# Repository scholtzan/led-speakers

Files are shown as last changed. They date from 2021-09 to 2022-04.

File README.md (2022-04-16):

# 3D Printed Reactive LED Speakers

This repository contains all the model files, assembly instructions and code files for building reactive LED speakers.

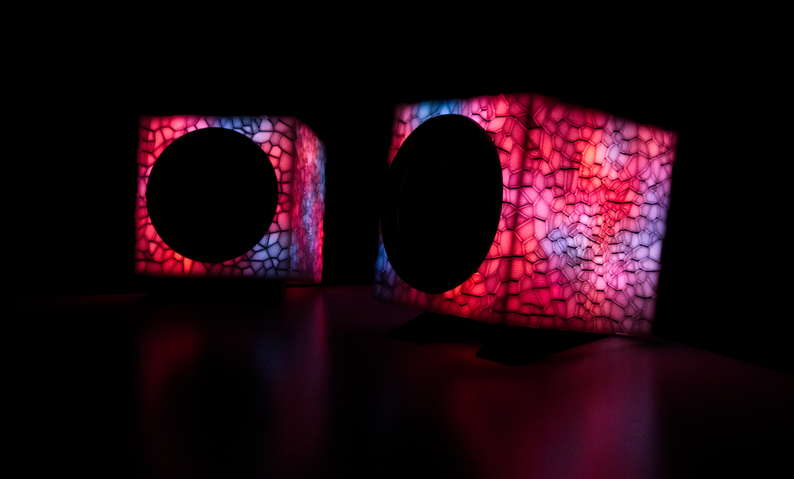
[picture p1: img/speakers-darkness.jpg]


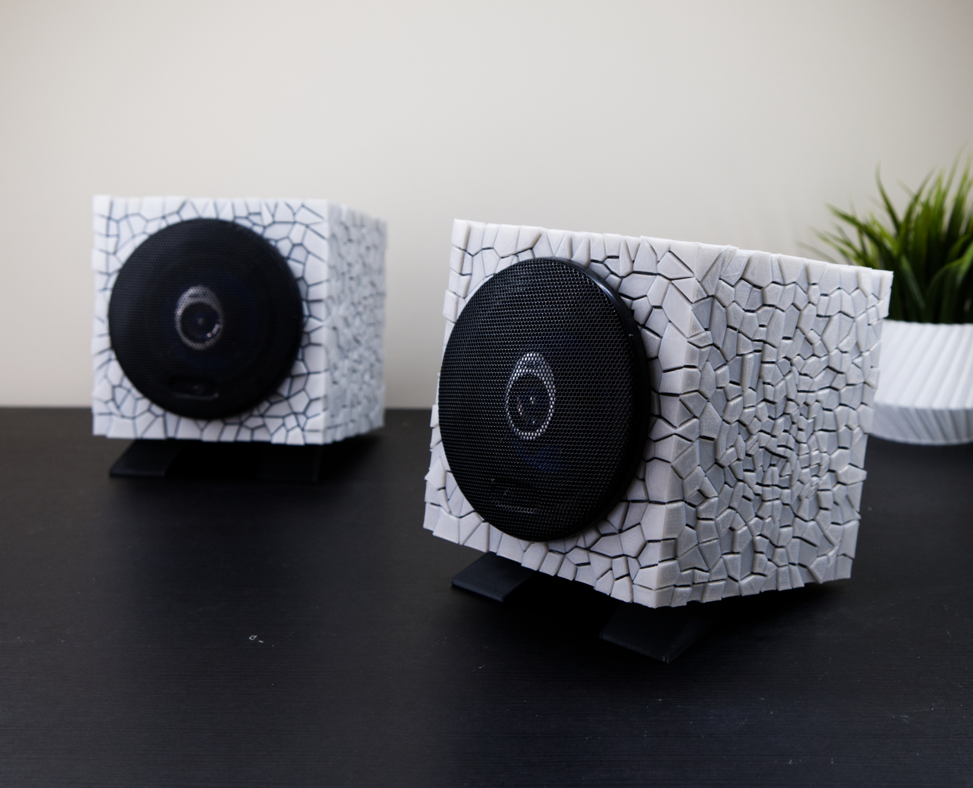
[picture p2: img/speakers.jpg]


## Demo

_Watch a demo of the speakers on Youtube:_

Youtube video (https://www.youtube.com/watch?v=SGH6p20TAoc)

## Overview

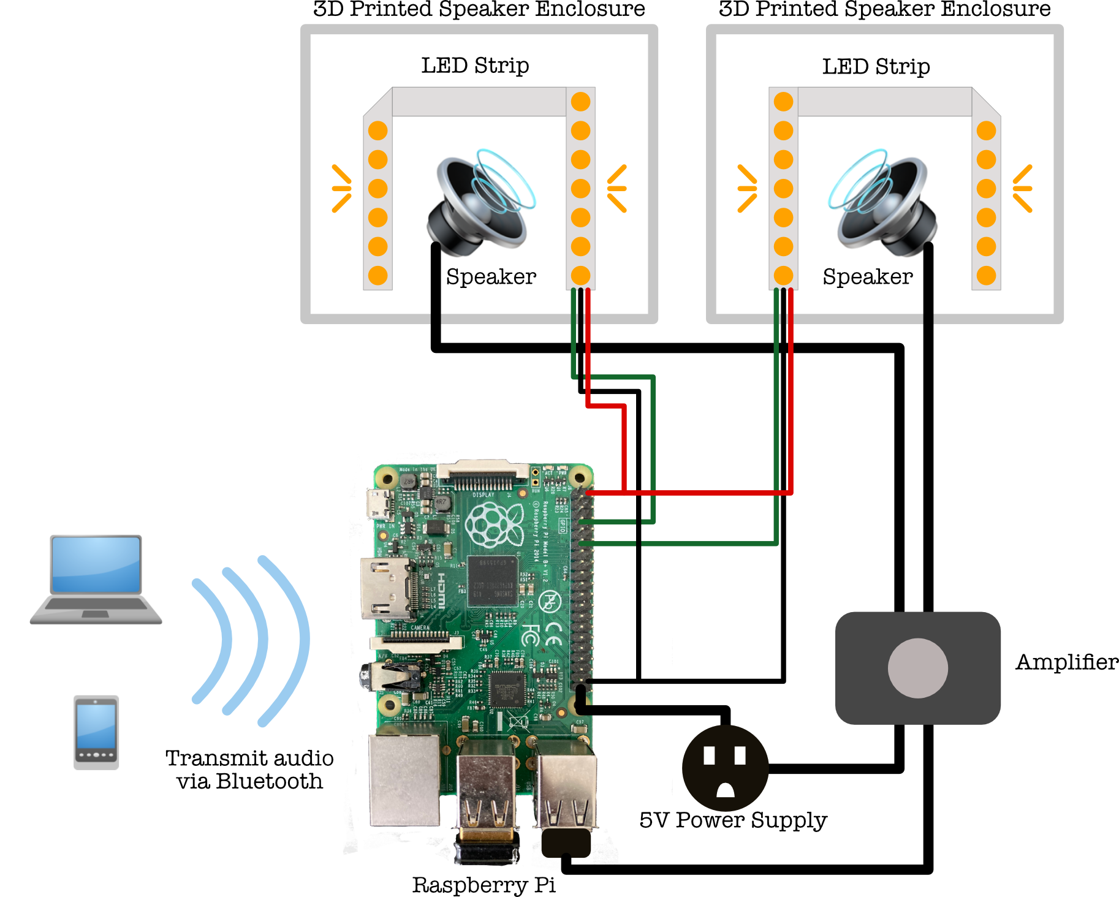
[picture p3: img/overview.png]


The entire setup consists of two speakers which are composed of a 3D printed enclosure that contains the speaker cone and a 1.5m long LED strip.
The enclosure is mainly printed from transparent PLA+ with some black accents. The speakers are connected to an amplifier which gets its audio
input from a Raspberry Pi. Devices, like phones or PCs can connect to the Raspberry Pi via Bluetooth to play audio. The audio input is processed 
to create different visual patterns on the connected LED strips. 

## Required Materials

* Raspberry Pi
    * Ideally a Raspberry Pi 4, since it has in-built Bluetooth and Wifi
    * Older versions also work but need additional dongles for Bluetooth
* 5V power supply
* Amplifier
* 3m RGB LED strip
    * 1.5m for each speaker
* 4-inch speakers
* 4mm Dual Banana Jack Socket Binding Post to 2 Screws Adapter Connector
    * For connecting the Amplifier to the Speakers
* Wire
    * For connecting all the components
* Heat shrink tubes
    * For insulating soldered wires
* Soldering iron + solder
* Hot glue gun + Hot glue
* Clear PLA+
    * Enclosure
* Black PLA+
    * Inner LED cage, stand, enclosure
* [optional] Glow-in-the-dark filament
    * The last few upper layers can be printed with Glow-in-the-dark filament for some interesting glow-in-the-dark effects

## 3D Printed Enclosure

The speaker enclosure consists of multiple parts that can be found in the `model/` directory.

The outer enclosure walls are printed from clear PLA+. For a better contrast of the rough structure, the gaps are printed in black PLA.
To change filament mid-print, the [Multicolor prints with a single extruder in Cura](https://github.com/scholtzan/cura-multicolor-single-extruder) plugin
can be used.


_Printed walls_

The LED strip will be cut into smaller strips that will get attached to an inner cage to stay in place.
All parts of the cage are printed in PLA and glued together using hot glue.


_Parts for assembling the inner cage_

The assembled cage with the LEDs glued on is then attached to one of the enclosure walls.

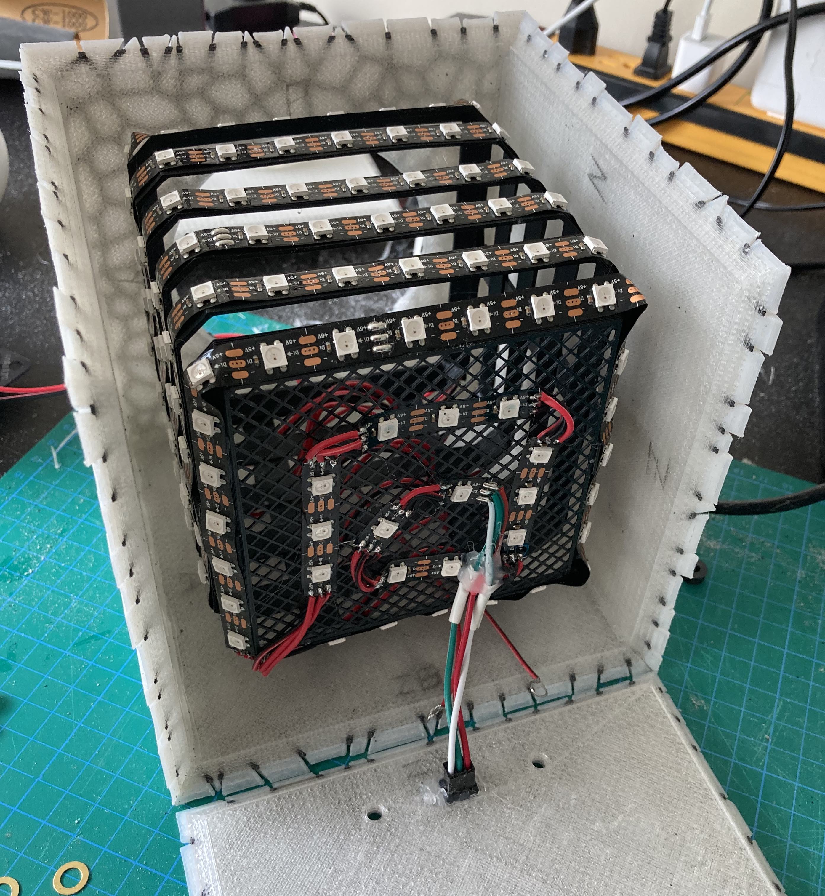
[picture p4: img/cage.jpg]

_Assembled cage with LEDs_

### Print Settings

**Walls**:
* Infill: 50%
* Infill Pattern: Gyroid
* Layer Height: 0.3mm
* Support: no

**Inner cage:**
* Infill: 15%
* Layer Height: 0.3mm
* Support: no

## Raspberry Pi Setup

Currently, only USB input is supported. Connect the amplifier to the Raspberry Pi using USB and connect the LED strips to the SPI pins
of the Raspberry Pi. A 5V power supply is used to power the Raspberry Pi as well as the LED strips. The amplifier uses a separate power supply.

All of these components (except for the amplifier) are placed in a separate printed enclosure.

### Audio Setup

_Based on [Another How to turn your Pi in a Bluetooth Speaker Tutorial](https://forums.raspberrypi.com/viewtopic.php?t=235519)_

Install Pulseaudio and bluetooth module:
```sudo apt-get install pulseaudio pulseaudio-module-bluetooth```

Add user to group `bluetooth`:
```
sudo usermod -a -G bluetooth pi
sudo reboot
```

Make discoverable:
```
sudo nano /etc/bluetooth/main.conf

...
Class = 0x41C
DiscoverableTimeout = 0
...

sudo systemctl restart bluetooth
```

In `bluetoothctl`, setup Bluetooth:
```
pi@raspberrypi:~ $ bluetoothctl
[NEW] Controller XX:XX:XX:XX:XX:XX raspberrypi [default]
[bluetooth]# power on
Changing power on succeeded
[bluetooth]# discoverable on
Changing discoverable on succeeded
[CHG] Controller XX:XX:XX:XX:XX:XX Discoverable: yes
[bluetooth]# pairable on
Changing pairable on succeeded
[bluetooth]# agent on
Agent registered
[bluetooth]# default-agent
Default agent request successful
[bluetooth]# quit
Agent unregistered
[DEL] Controller XX:XX:XX:XX:XX:XX raspberrypi [default]
```

Start Pulseaudio and check status:
```
pulseaudio --start

sudo systemctl status bluetooth
```

Start Pulseaudio on boot
```
systemctl --user enable pulseaudio
```

Auto-pairing
```
sudo apt-get install bluez-tools

sudo nano /etc/systemd/system/bt-agent.service

[Unit]
Description=Bluetooth Auth Agent
After=bluetooth.service
PartOf=bluetooth.service

[Service]
Type=simple
ExecStart=/usr/bin/bt-agent -c NoInputNoOutput

[Install]
WantedBy=bluetooth.target

sudo systemctl enable bt-agent
```

Disable onboard Bluetooth module in favour of Bluetooth dongle:
```
sudo nano /etc/modprobe.d/blacklist-bluetooth.conf

blacklist btbcm
blacklist hci_uart
```

Controlling volume:
```
sudo nano /etc/systemd/system/bluetooth.target.wants/bluetooth.service

...
ExecStart=/usr/lib/bluetooth/bluetoothd --noplugin=avrcp
...
```

### LED

Use SPI for LED strip:
```
/boot/cmdline.txt 
```

append 
```
spidev.bufsiz=32768

core_freq=500
core_freq_min=500
```

## Software

### Server

Install [cross](https://github.com/rust-embedded/cross)

Build docker container with libpulse installed:

`docker build -t rbp-cross . `

Build project

`cross build --target=armv7-unknown-linux-gnueabihf --release`

### Web App

Go to the `web/` folder: `cd web/`

Update the `.env` file and set the correct host and ports.

To build the web app run: `make`

### Installation

Once the server and web app have been built successfully, copy the `led_speakers` binary, the `web/static` directory and the `config.json` file on to the Raspberry Pi.

The software can be manually started by running `./led_speakers` and the web app will be ready to be accessed under the configured host and port.

Settings can be changed in the `config.json` file.

To start the software automatically when booting, create a custom systemd service:

`sudo nano ~/.config/systemd/user/led-speakers.service`

```
[Unit]
Description=LED Speakers Service

[Service]
Type=idle
ExecStart=/home/pi/led_speakers
Restart=on-failure
RestartSec=60

[Install]
WantedBy=default.target
```

To enable the service:

```
systemctl --user enable led-speakers.service
systemctl --user daemon-reload
```

### Settings

Settings can be changed in the `config.json` file:

```json
{
    // available visualizations and default configurations
    "visualizations": {
        "rotating_viz": {
            "pretty_name": "Rotating Viz",
            "speed": 5.0,
            "falloff": 0.1
        },
        "sparkle_viz": {
            "pretty_name": "Sparkle Viz",
            "falloff": 0.1,
            "speed": 5.0,
            "max_ignite": 2.0
        },
        "solid_viz": {
            "pretty_name": "Solid Viz"
        },
        "center_viz": {
            "pretty_name": "Center Viz"
        },
        "solid_beat_viz": {
            "pretty_name": "Solid Beat Viz",
            "fade_colors": true,
            "fade_duration": 20
        },
        "fading_beat_viz": {
            "pretty_name": "Fading Beat Viz",
            "fade_duration": 1,
            "fade_threshold": 10,
            "frequency_magnitude_buffer_size": 300
        },
        "blend_viz": {
            "pretty_name": "Blend Viz",
            "spread": 6,
            "blend_speed": 3,
            "offset_weight": 1,
            "blend_factor": 10
        }
    },
    // configures the pins that control the LED strip
    "output": {
        "left": {
            "spi": "/dev/spidev0.0",
            "total_leds": 150
        },
        "right": {
            "spi": "/dev/spidev1.0",
            "total_leds": 150
        }
    },
    // default themes
    "themes": [
        {
            "name": "Rainbow",
            "colors": [
                [255, 0, 0],
                [255, 100, 0],
                [255, 200, 0],
                [100, 255, 0],
                [0, 255, 0],
                [0, 255, 100],
                [0, 255, 255],
                [0, 100, 255],
                [0, 0, 255],
                [100, 0, 255],
                [255, 0, 255]
            ]
        },
        {
            "name": "Test Theme",
            "colors": [
                [255, 0, 0]
            ]    
        }
    ],
    // parameters for the audio transformation
    "transformer": {
        "sink": "alsa_output.usb-Generic_USB2.0_Device_20170726905959-00.analog-stereo",
        "fft_len": 3000,
        "total_bands": 6,
        "lower_cutoff": 50.0,
        "upper_cutoff": 10000.0,
        "monstercat": 50.0,
        "decay": 10.0,
        "buffer_size": 65535
    },
    // host and port web app is hosted under
    "server_host": "127.0.0.1",
    "server_port": "8000"
}
```

### More docs

More detailed docs about certain aspects of the software can be found in [`docs/`](https://github.com/scholtzan/led-speakers/tree/main/docs)

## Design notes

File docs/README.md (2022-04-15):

# Software docs

Some more information about the software doing the audio processing and visualizations can be found in this directory:

* [Audio Input](https://github.com/scholtzan/led-speakers/blob/main/docs/audio.md)
* [Audio Transformation](https://github.com/scholtzan/led-speakers/blob/main/docs/transform.md)
* [Visualization](https://github.com/scholtzan/led-speakers/blob/main/docs/visualization.md)

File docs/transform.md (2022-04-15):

# Audio Processing and Transformation

The `AudioTransformer` initializes a new audio stream and starts the FFT based on the audio samples written to the audio buffer.

[todo: add more docs]

## FFT

To get frequency information about the audio input (dividing into frequency components). Frequency components are sinus oscillations with certain amplitude an dphase. 
Sampling rate = average number of samples obtained in one second
Maximum frequency that can be observed = sampling rate / 2
Measurement duration = block length = number of samples to analyse

convert fft into smaller number of buckets reperesnting average magnitude of frequencies they represent
log magnitude instead of linear frequency

averaging spectra
* exponential mean
    * weighting is inversely propotional to age of result (oldest measurement taken into account least)

frequency magnitutes gets determined frequencies as input after FFT

frequency constant ~= 2.4

distribution coefficient = [-frequency constant; 0]

cutoff frequencies = [0; upper cutoff]

frequency = [0; 1]

upper cutoff = lower cutoff

band_frequency_magnitude = sqrt(avg_magnitude * (2 + n))

resampling/rebinning a spectrum
https://dsp.stackexchange.com/questions/129/how-can-i-compute-a-log-spaced-power-spectrum/2098#2098

The log scale more closely matches our perception of the sound spectrum.

Our perception makes us feel that C1 is the same distance from C2 as C2 is from C3 (they are each an octave apart, the same distance, right?). But their actual frequencies are doubled, rather than going up a fixed amount. There are many scientific reasons for this, but basically our ears respond 'logarithmically' to both level (volume) and frequency.

A logarithmic scale means that each octave occupies the same 'width' across the spectrum. This makes it easier to judge certain things. On a linear scale, though the frequencies are even distances apart, if you were to plot the octave band limits, you would see them getting further apart as you go along the axis. It is confusing stuff, i know, but basically it all boils down to the fact that most properties of sound are analysed logarithmically, unless you are pinpointing a specific frequency.

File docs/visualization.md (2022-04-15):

# Visualization

All visualizations implement the `Viz` trait:

```rust
#[typetag::serde]
/// Abstract type implemented by all visualizations.
pub trait Viz: DynClone + Sync + Send {
    /// Returns the unique identifier of the visualization.
    fn get_name(&self) -> &str;

    /// Returns a descriptive visualization name.
    fn get_pretty_name(&self) -> &str;

    /// Updates the visualization state based on the provided input.
    fn update(&mut self, input: &Vec<f32>, colors: &Vec<Color>) -> Vec<PixelViz>;

    /// Sets the number of total available pizels.
    fn set_total_pixels(&mut self, pixels: usize);

    /// Updates the settings.
    fn update_settings(&mut self, settings: HashMap<String, String>);

    /// Returns the viz settings as map.
    fn get_settings(&self) -> HashMap<String, String>;
}
```

The `update` method is where the pixel/LED colors will get updated in each iteration.

[todo]

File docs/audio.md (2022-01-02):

# Audio Input

Audio is captured and written to a buffer from the configured audio sink using Pulseaudio.

## Initialization

A new `Buffer` is created which samples will be written to. A temporary PulseAudio main loop and context are being created for connecting to the configured audio source. The PulseAudio main loop it thread safe and iteratively executes `poll` system calls and dispatches fired events. The PulseAudio context is used for asynchronously communicating with the PulseAudio server.

The configuration file specifies the name of the sink audio is received from. This name is used for finding the audio source owning the sink and connecting to it.

## Connecting to source and stream

As a threaded PulseAudio is used, it is necessary for locks to be held whenever a PulseAudio function is called that used an object assicated with the main loop. Callbacks are by default asynchronous. To make them synchronous the callback needs to signal to the main loop when it has been called.

Once connected to the correct audio source, the audio stream is initialized. The stream is connected to the configured source.

## Reading from stream

After the stream has been successfully connected to the source, bytes can be read from the stream. Data is read from the stream in batches, so reading from the stream is paused until a certain threshold of bytes available is reached. Data read from the stream is written into the previously created buffer.
Since the buffer has a limited size, data is removed when reading from it. It is possible that the buffer does not have enough space left when trying to write to it. If that is the case then writing is paused for a short period of time and retried for a few times after. 

Reading data from the audio source is moved into a separate thread in order to ensure reading audio data and processing it can happen concurrently.

The data written to the buffer is used by `AudioTransformer` to transform the bytes into audio bands that can be visualized.

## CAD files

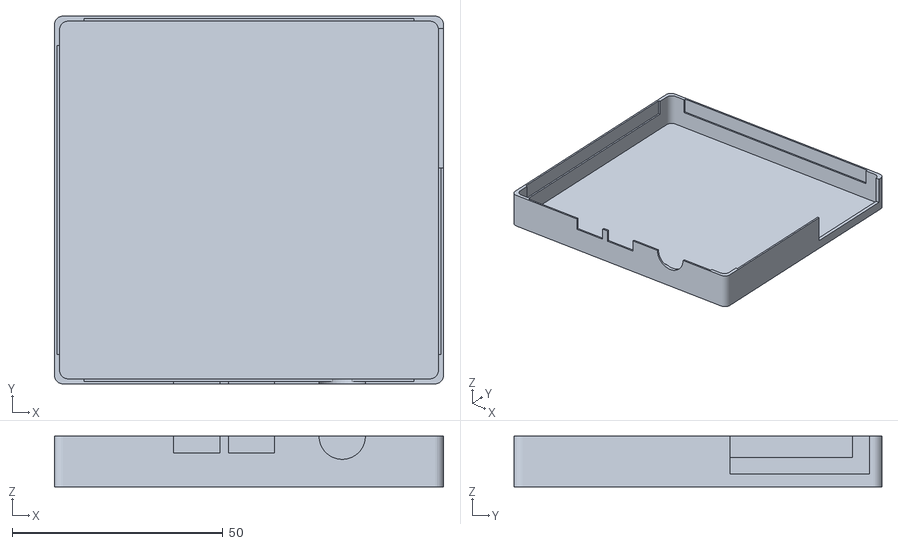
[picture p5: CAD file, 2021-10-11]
model/case-top.stl
92.2 x 87.2 x 12.0

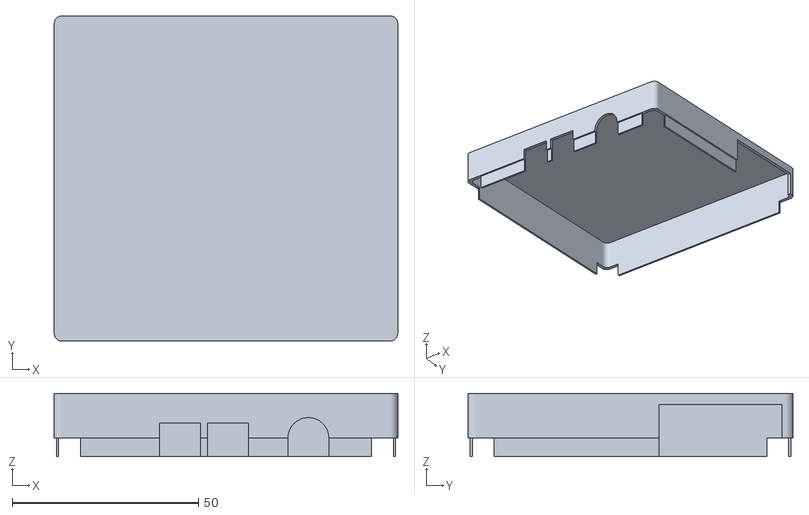
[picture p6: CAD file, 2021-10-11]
model/case-bottom.stl
92.2 x 87.2 x 17.0

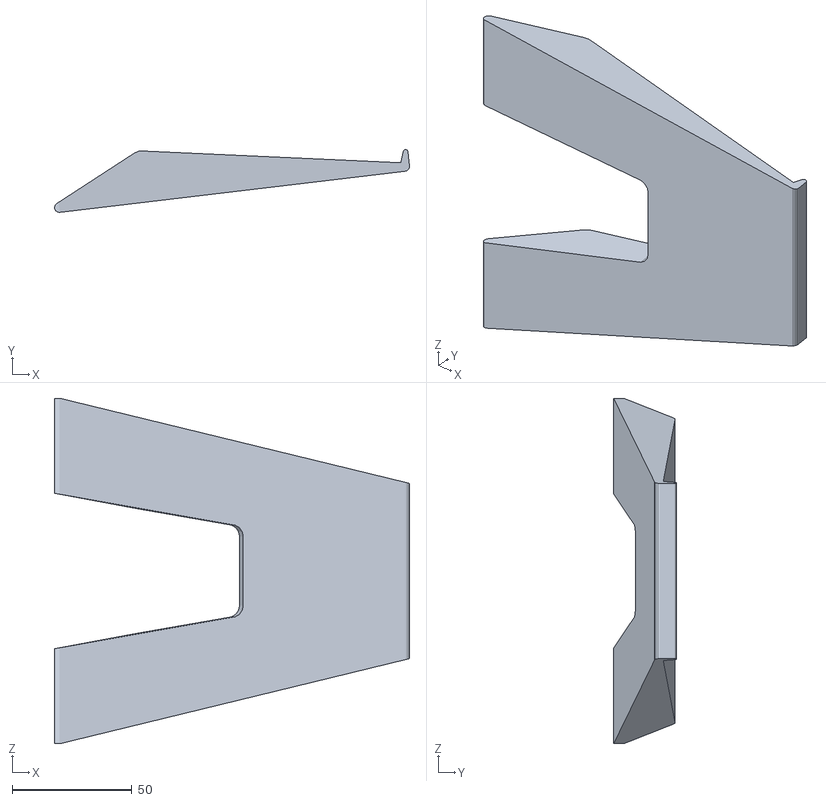
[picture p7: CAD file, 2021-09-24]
model/stand.stl
148.0 x 26.2 x 144.0

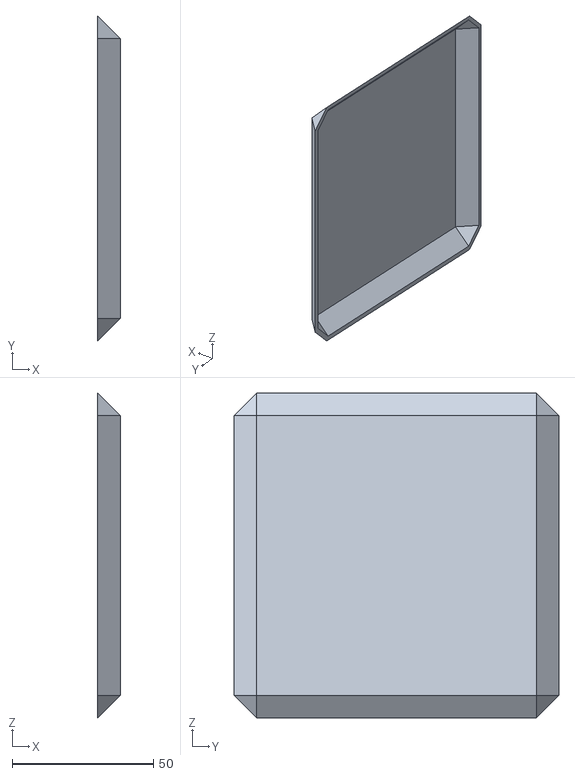
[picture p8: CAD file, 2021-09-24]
model/inner-cage-back.stl
8.00 x 115.0 x 115.0

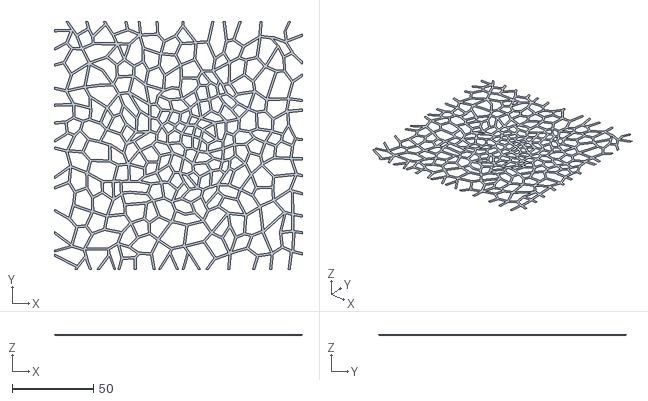
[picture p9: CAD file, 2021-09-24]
model/wall-bottom-solid.stl
152.8 x 152.8 x 0.6

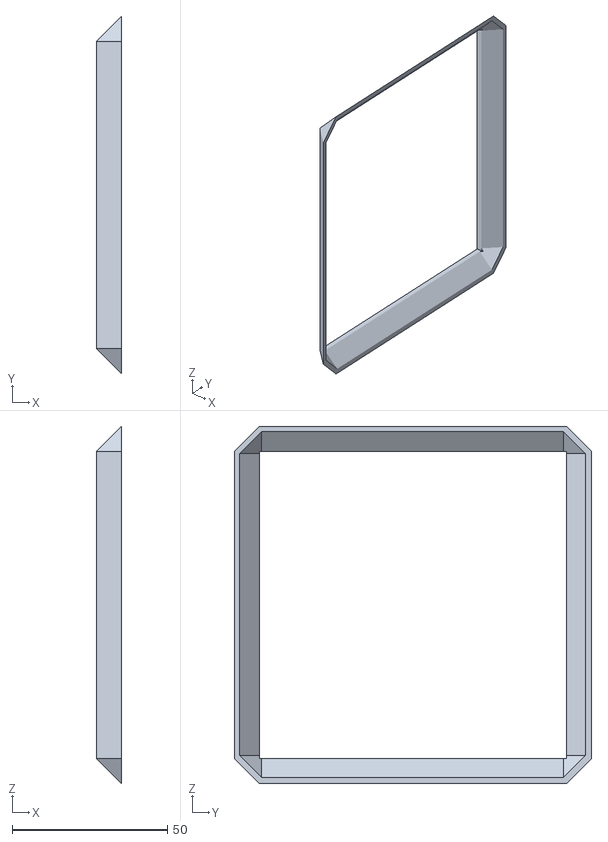
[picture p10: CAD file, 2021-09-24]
model/inner-cage-front.stl
8.00 x 115.0 x 115.0

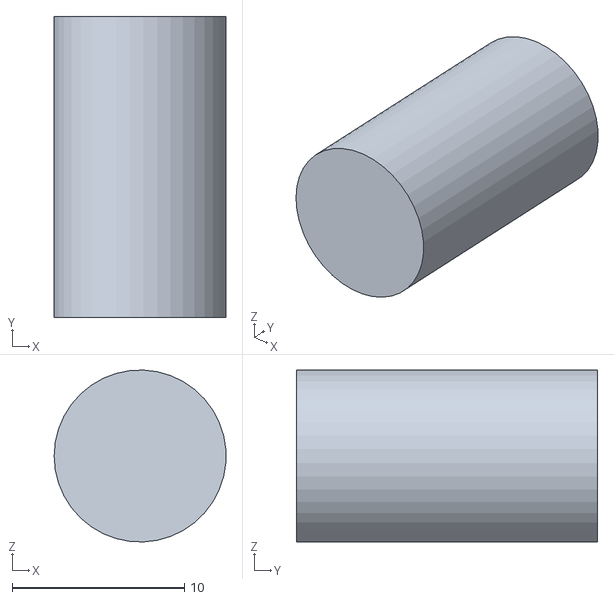
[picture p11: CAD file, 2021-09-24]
model/inner-cage-leg.stl
9.98 x 17.5 x 9.99

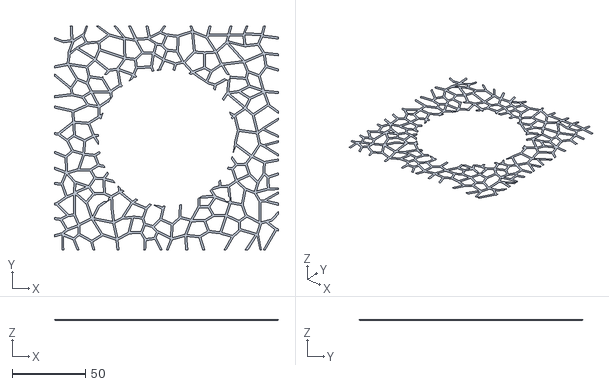
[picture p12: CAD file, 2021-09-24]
model/wall-front-solid.stl
152.8 x 152.8 x 0.6

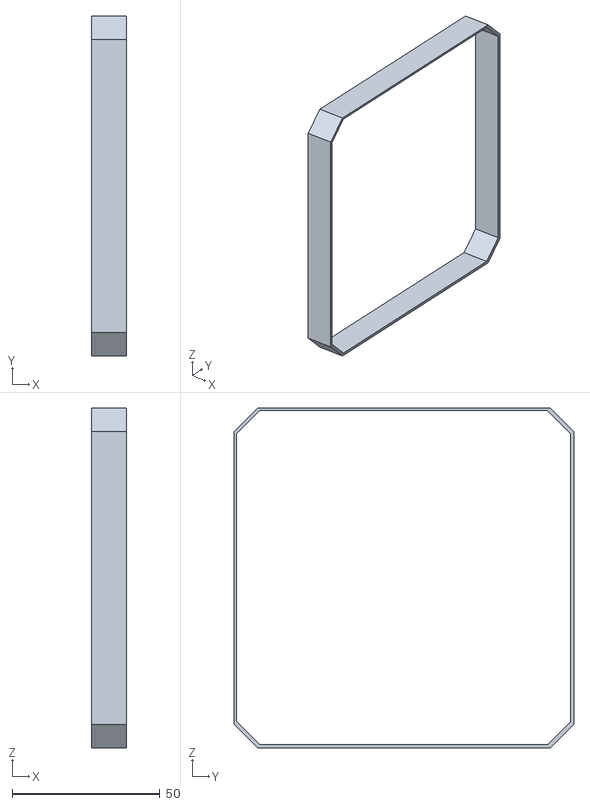
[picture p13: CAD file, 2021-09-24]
model/inner-cage-center.stl
12.0 x 115.0 x 115.0

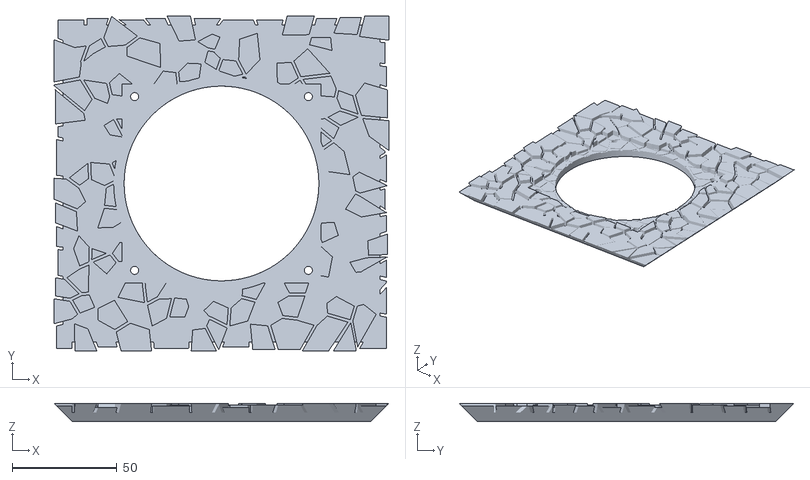
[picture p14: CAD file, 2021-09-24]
model/wall-front-transparent.stl
160.0 x 160.0 x 8.60

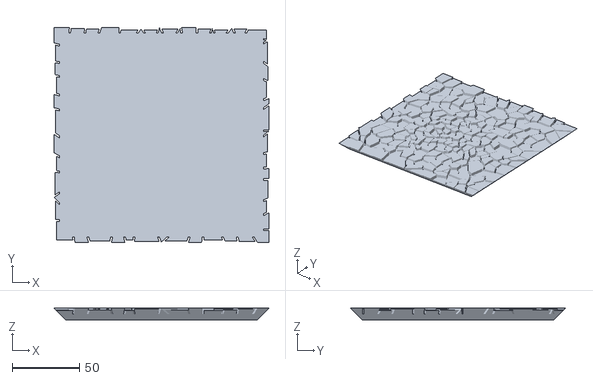
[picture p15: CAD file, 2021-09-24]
model/wall-3-transparent.stl
160.0 x 160.0 x 8.60

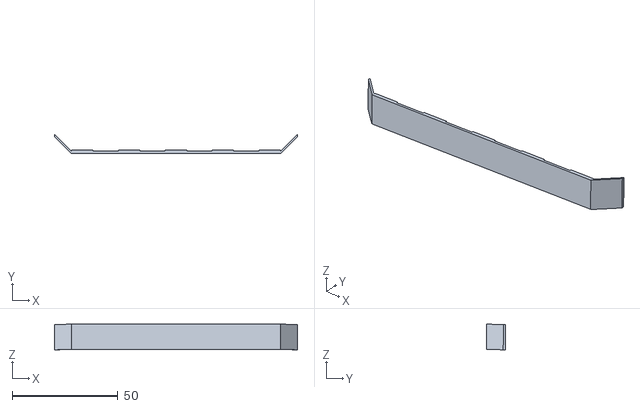
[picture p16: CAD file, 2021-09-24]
model/inner-cage-connector-strip.stl
115.0 x 9.20 x 12.2

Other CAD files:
model/wall-back-solid.stl
model/wall-back-transparent.stl
model/wall-2-transparent.stl
model/wall-3-solid.stl
model/wall-1-transparent.stl
model/wall-1-solid.stl
model/audio-jack-spacers.stl
model/wall-2-solid.stl
model/wall-bottom-transparent.stl

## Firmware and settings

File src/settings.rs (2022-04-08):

use serde::de::Error;
use serde::{Deserialize, Deserializer, Serialize};
use serde_json::Value;

use crate::led::Led;
use crate::theme::Theme;
use crate::viz::{
    BlendViz, BlendVizConfig, CenterViz, CenterVizConfig, FadingBeatViz, FadingBeatVizConfig,
    RotatingViz, RotatingVizConfig, SolidBeatViz, SolidBeatVizConfig, SolidViz, SolidVizConfig,
    SparkleViz, SparkleVizConfig, Viz,
};
use std::collections::HashMap;

#[derive(Serialize, Deserialize, Clone)]
/// Settings for a single output
pub struct Output {
    /// SPI for output
    pub spi: String,

    /// Total available LEDs for output
    pub total_leds: i32,
}

impl Output {
    /// Converts output settings to an `Led` instance.
    pub fn to_led(&self) -> Led {
        Led::new(self.total_leds, &self.spi)
    }
}

#[derive(Serialize, Deserialize, Clone)]
/// Settings for left and right outputs.
pub struct OutputSettings {
    /// Left output settings
    pub left: Output,

    /// Right output settings
    pub right: Output,
}

#[derive(Serialize, Deserialize, Clone)]
pub struct TransformerSettings {
    /// Audio sink name
    pub sink: String,

    /// Number of FFT output buckets
    pub fft_len: usize,

    /// Number of total audio bands
    pub total_bands: usize,

    /// Lower cutoff frequency
    pub lower_cutoff: f32,

    /// Upper cutoff frequency
    pub upper_cutoff: f32,

    /// Monstercat smoothing factor
    pub monstercat: f32,

    /// Decay factor
    pub decay: f32,

    /// Audio buffer size
    pub buffer_size: usize,
}

impl TransformerSettings {
    /// Transform the settings into a map of string values.
    pub fn to_map(&self) -> HashMap<String, String> {
        let mut settings = HashMap::new();
        settings.insert("sink".to_string(), self.sink.clone());
        settings.insert("fft_len".to_string(), self.fft_len.to_string());
        settings.insert("total_bands".to_string(), self.total_bands.to_string());
        settings.insert("lower_cutoff".to_string(), self.lower_cutoff.to_string());
        settings.insert("upper_cutoff".to_string(), self.upper_cutoff.to_string());
        settings.insert("monstercat".to_string(), self.monstercat.to_string());
        settings.insert("decay".to_string(), self.decay.to_string());
        settings.insert("buffer_size".to_string(), self.buffer_size.to_string());
        settings
    }

    /// Create transformer settings from map of string values.
    pub fn from_map(settings: HashMap<String, String>) -> Self {
        TransformerSettings {
            sink: settings
                .get(&"sink".to_string())
                .unwrap_or(&"".to_string())
                .to_string(),
            fft_len: settings
                .get(&"fft_len".to_string())
                .unwrap_or(&"0".to_string())
                .parse::<usize>()
                .unwrap(),
            total_bands: settings
                .get(&"total_bands".to_string())
                .unwrap_or(&"0".to_string())
                .parse::<usize>()
                .unwrap(),
            lower_cutoff: settings
                .get(&"lower_cutoff".to_string())
                .unwrap_or(&"0".to_string())
                .parse::<f32>()
                .unwrap(),
            upper_cutoff: settings
                .get(&"upper_cutoff".to_string())
                .unwrap_or(&"0".to_string())
                .parse::<f32>()
                .unwrap(),
            monstercat: settings
                .get(&"monstercat".to_string())
                .unwrap_or(&"0".to_string())
                .parse::<f32>()
                .unwrap(),
            decay: settings
                .get(&"decay".to_string())
                .unwrap_or(&"0".to_string())
                .parse::<f32>()
                .unwrap(),
            buffer_size: settings
                .get(&"buffer_size".to_string())
                .unwrap_or(&"0".to_string())
                .parse::<usize>()
                .unwrap(),
        }
    }
}

#[derive(Serialize, Deserialize)]
/// Representation of the config.json file.
pub struct Settings {
    #[serde(deserialize_with = "parse_visualizations")]
    /// Available visualizations
    pub visualizations: Vec<Box<dyn Viz>>,

    /// Output settings
    pub output: OutputSettings,

    /// Available themes
    pub themes: Vec<Theme>,

    pub transformer: TransformerSettings,

    /// Server host IP
    pub server_host: String,

    /// Server host port
    pub server_port: String,
}

impl Settings {
    /// Update the transformer related settings.
    pub fn apply_transformer_settings(&mut self, transformer_settings: TransformerSettings) {
        self.transformer = transformer_settings;
    }
}

/// Creates a new visualization from the settings.
fn parse_visualizations<'de, D>(d: D) -> Result<Vec<Box<dyn Viz>>, D::Error>
where
    D: Deserializer<'de>,
{
    let parsed = Value::deserialize(d)?;
    parsed
        .as_object()
        .unwrap()
        .into_iter()
        .map(|(name, args)| {
            let viz: Result<Box<dyn Viz>, D::Error> = match name.as_str() {
                "rotating_viz" => {
                    let viz_config: RotatingVizConfig =
                        serde_json::from_value(args.clone()).unwrap();
                    Ok(Box::new(RotatingViz::new(viz_config)))
                }
                "sparkle_viz" => {
                    let viz_config: SparkleVizConfig =
                        serde_json::from_value(args.clone()).unwrap();
                    Ok(Box::new(SparkleViz::new(viz_config)))
                }
                "solid_viz" => {
                    let viz_config: SolidVizConfig = serde_json::from_value(args.clone()).unwrap();
                    Ok(Box::new(SolidViz::new(viz_config)))
                }
                "center_viz" => {
                    let viz_config: CenterVizConfig = serde_json::from_value(args.clone()).unwrap();
                    Ok(Box::new(CenterViz::new(viz_config)))
                }
                "blend_viz" => {
                    let viz_config: BlendVizConfig = serde_json::from_value(args.clone()).unwrap();
                    Ok(Box::new(BlendViz::new(viz_config)))
                }
                "solid_beat_viz" => {
                    let viz_config: SolidBeatVizConfig =
                        serde_json::from_value(args.clone()).unwrap();
                    Ok(Box::new(SolidBeatViz::new(viz_config)))
                }
                "fading_beat_viz" => {
                    let viz_config: FadingBeatVizConfig =
                        serde_json::from_value(args.clone()).unwrap();
                    Ok(Box::new(FadingBeatViz::new(viz_config)))
                }
                _ => Err(D::Error::custom(format!("Unknown {:?}", name.as_str()))),
            };
            viz
        })
        .collect::<Result<Vec<Box<dyn Viz>>, D::Error>>()
}

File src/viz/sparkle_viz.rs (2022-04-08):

use chrono::prelude::*;

use rand::seq::SliceRandom;

use serde::{Deserialize, Serialize};
use std::collections::HashMap;

use crate::theme::Color;
use crate::viz::PixelViz;
use crate::viz::Viz;

#[derive(Serialize, Deserialize, Debug, PartialEq, Clone)]
pub struct SparkleVizConfig {
    /// Screen friendly name of visualization.
    pub pretty_name: String,

    /// Determines how frequently pixels should be ignited.
    pub speed: f32,

    /// Factor of how much brightness is reduced.
    pub falloff: f32,

    /// Maximum number of pixels ignited at the same time representing the same frequency.
    pub max_ignite: f32,
}

impl SparkleVizConfig {
    /// Convert settings in map of strings to visualization config.
    pub fn to_map(&self) -> HashMap<String, String> {
        let mut settings = HashMap::new();
        settings.insert("speed".to_string(), self.speed.to_string());
        settings.insert("falloff".to_string(), self.falloff.to_string());
        settings.insert("max_ignite".to_string(), self.max_ignite.to_string());
        settings
    }

    /// Create visualization config from map of strings.
    pub fn from_map(name: String, settings: HashMap<String, String>) -> Self {
        Self {
            pretty_name: name,
            falloff: settings
                .get(&"falloff".to_string())
                .unwrap_or(&"0".to_string())
                .parse::<f32>()
                .unwrap(),
            speed: settings
                .get(&"speed".to_string())
                .unwrap_or(&"0".to_string())
                .parse::<f32>()
                .unwrap(),
            max_ignite: settings
                .get(&"max_ignite".to_string())
                .unwrap_or(&"0".to_string())
                .parse::<f32>()
                .unwrap(),
        }
    }
}

#[derive(Deserialize, Serialize, Clone)]
/// Visualization randomly igniting pixels for a short amount of time.
/// The pixel color is determined by the frequency bands and their magnitudes.
pub struct SparkleViz {
    /// Visualization config.
    pub config: SparkleVizConfig,

    /// Total number of pixels.
    total_pixels: usize,

    /// Falloff factors applied to each pixel.
    falloffs: Vec<f32>,

    /// Elapsed time since last time pixels got ignited.
    elapsed_time: DateTime<Utc>,

    /// Pixel colors.
    pixels: Vec<Option<PixelViz>>,
}

#[typetag::serde]
impl Viz for SparkleViz {
    fn get_name(&self) -> &str {
        "sparkle_viz"
    }

    fn get_pretty_name(&self) -> &str {
        &self.config.pretty_name
    }

    fn update(&mut self, input: &Vec<f32>, _colors: &Vec<Color>) -> Vec<PixelViz> {
        let total_bands = input.len();
        let _rng = rand::thread_rng();

        let now = Utc::now();
        let elapsed: f32 = (now - self.elapsed_time).num_milliseconds() as f32;

        if elapsed > 1000.0 / self.config.speed {
            self.elapsed_time = now;
            for band in 0..total_bands {
                // total number of pixels to ignite
                let total_ignite = ((input[band] / 100.0) * self.config.max_ignite) as usize;

                // pixels that are currently off
                let off_pixels = self
                    .pixels
                    .iter()
                    .enumerate()
                    .flat_map(|(i, p)| if let Some(_pixel) = p { None } else { Some(i) })
                    .collect::<Vec<usize>>();

                // randomly determine which off pixels should be ignited
                let pixels_to_spark: Vec<usize> = off_pixels
                    .choose_multiple(&mut rand::thread_rng(), total_ignite)
                    .cloned()
                    .collect();

                // set color
                for pixel in pixels_to_spark {
                    self.pixels[pixel] = Some(PixelViz {
                        color_index: band,
                        red_mul: 1.0,
                        green_mul: 1.0,
                        blue_mul: 1.0,
                        brightness: input[band] / 100.0,
                    });
                    self.falloffs[pixel] = 1.0;
                }
            }
        }

        // apply falloffs
        for (i, falloff) in self.falloffs.iter_mut().enumerate() {
            if let Some(ref mut pixel) = self.pixels[i] {
                if *falloff >= 1.0 {
                    pixel.brightness *= self.config.falloff;
                }
                if pixel.brightness <= 0.1 {
                    self.pixels[i] = None;
                }
            }
        }

        // map color_index -1 to off pixels
        let pixels = self
            .pixels
            .iter()
            .map(|p| {
                if let Some(pixel) = p {
                    return pixel.clone();
                } else {
                    return PixelViz {
                        color_index: 0,
                        red_mul: 0.0,
                        green_mul: 0.0,
                        blue_mul: 0.0,
                        brightness: 0.0,
                    };
                }
            })
            .collect::<Vec<PixelViz>>();

        pixels
    }

    fn set_total_pixels(&mut self, pixels: usize) {
        self.total_pixels = pixels;
        self.pixels = vec![None; pixels];
        self.falloffs = vec![0.0; pixels];
    }

    fn get_settings(&self) -> HashMap<String, String> {
        self.config.to_map()
    }

    fn update_settings(&mut self, settings: HashMap<String, String>) {
        let new_settings = SparkleVizConfig::from_map(self.get_pretty_name().to_string(), settings);
        self.config = new_settings;
        self.pixels = vec![None; self.total_pixels];
        self.falloffs = vec![0.0; self.total_pixels];
    }
}

unsafe impl Send for SparkleViz {}
unsafe impl Sync for SparkleViz {}

impl SparkleViz {
    pub fn new(config: SparkleVizConfig) -> Self {
        SparkleViz {
            config,
            total_pixels: 0,
            elapsed_time: Utc::now(),
            falloffs: Vec::new(),
            pixels: Vec::new(),
        }
    }
}

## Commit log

2021-09-24 Add model files
    [audio-jack-spacers.stl, case-bottom.stl, case-top.stl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]
2021-10-11 Update case
    [case-bottom.stl, case-top.stl]
2021-11-20 WIP threadunsafe audio
2021-11-28 Refactor to using threads
2021-12-27 Controlling LEDs
2021-12-28 rppal SPI LED version
2021-12-29 Change library for LEDs
2022-01-09 LED docs
2022-03-28 Show current theme colors on frontend
2022-04-09 Show on/off button on mobile
